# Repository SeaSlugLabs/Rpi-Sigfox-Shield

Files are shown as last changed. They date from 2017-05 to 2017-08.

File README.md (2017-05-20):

# Rpi-Sigfox-Shield
Documentation for Raspberry Pi Sigfox Board

The Wisol WSSFM10R2 is a Sigfox Module based on [Onsemi AX-SFUS](http://www.onsemi.com/pub/Collateral/AX-SFUS-D.PDF)

The WSSFM10R2 uses a UART interface. Simple commands are used to operate the module(see DataSheet).

This Board fits on Raspberry Pi 3, 2, B+, A+, Zero and Zero W.

Find on this repository the information about board. And some python examples to send information via Sigfox Network.

Dont forget to buy our products at [Sea Slug Labs IoT Maker Store](http://www.seasluglabs.io)

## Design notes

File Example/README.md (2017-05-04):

# Rpi-Sigfox-Shield
This is an screenshot Example

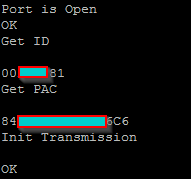
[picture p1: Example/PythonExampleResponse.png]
solarized dualmode


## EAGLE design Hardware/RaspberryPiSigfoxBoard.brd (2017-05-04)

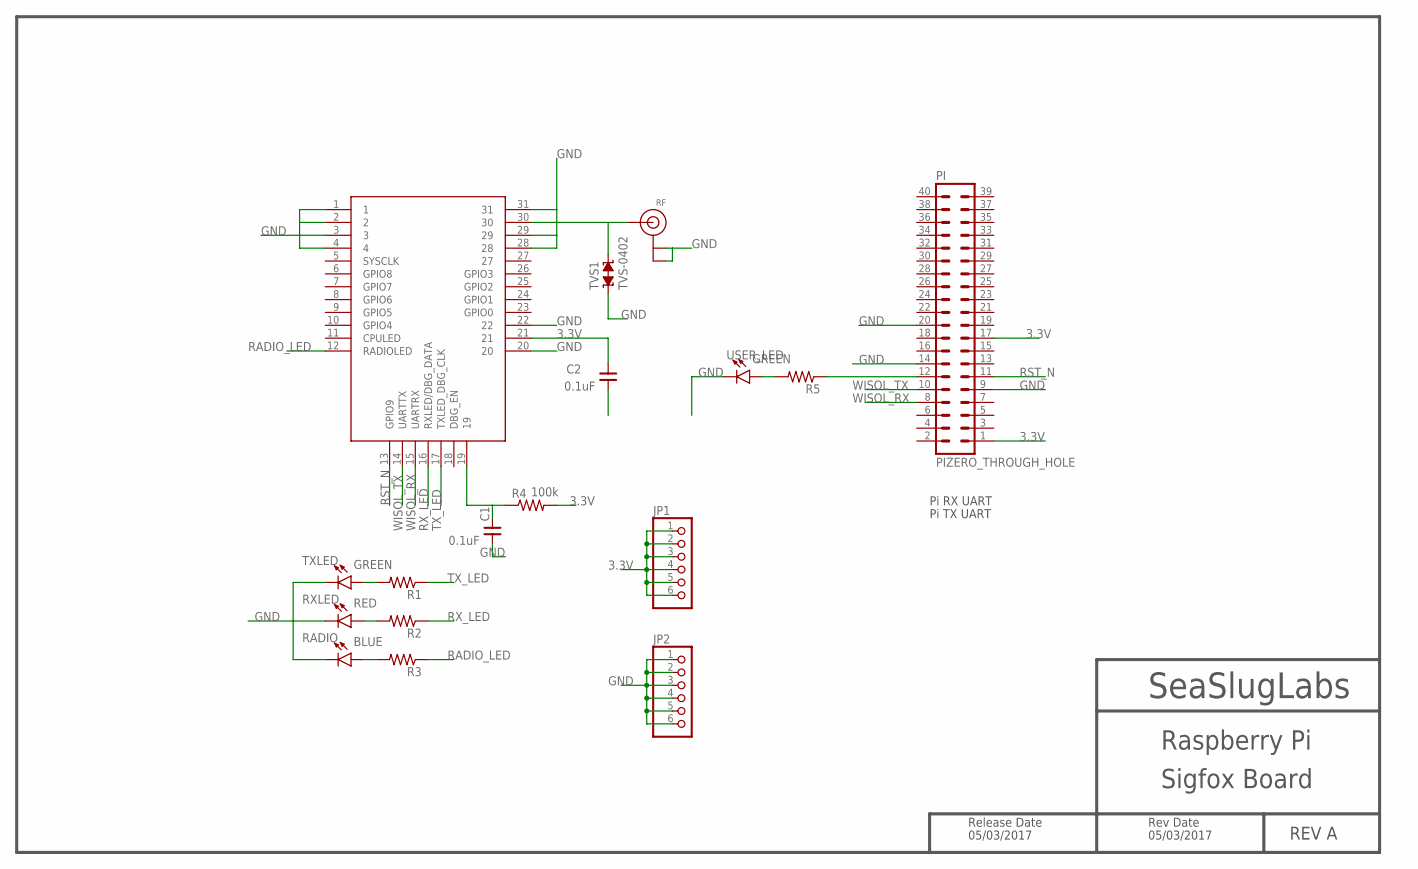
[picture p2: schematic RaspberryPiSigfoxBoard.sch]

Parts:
C1, C2: 0.1uF; 0402
JP1, JP2: PINHD-1X6B; 1X06-BIG
PI: PIZERO_THROUGH_HOLE; PIZERO_THOUGH_HOLE
R1, R2, R3, R5: R-US_R0402; R0402
R4: 100k; R0402
RADIO: BLUE; LED-0603
RF: ANTENNA_U.FL; U.FL
RXLED: RED; LED-0603
TVS1: TVS-0402; TVS0402
TXLED: GREEN; LED-0603
USER_LED: GREEN; LED-0603
WSSFM10R2: WSSFM10R2/R4WSSFM10R2R4; WISOL

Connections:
3.3V: C2.2, JP1.1, JP1.2, JP1.3, JP1.4, JP1.5, JP1.6, PI.1, PI.17, R4.2, WSSFM10R2.21
GND: C1.1, C2.1, JP2.1, JP2.2, JP2.3, JP2.4, JP2.5, JP2.6, PI.9, PI.14, PI.20, RADIO.C, RF.1 (GND), RF.2 (GND), RXLED.C, TVS1.1, TXLED.C, USER_LED.C, WSSFM10R2.1, WSSFM10R2.2, WSSFM10R2.3, WSSFM10R2.4, WSSFM10R2.20, WSSFM10R2.22, WSSFM10R2.28, WSSFM10R2.29, WSSFM10R2.31
unnamed: C1.2, R4.1, WSSFM10R2.19
unnamed: R1.2, TXLED.A
unnamed: R2.2, RXLED.A
unnamed: R3.2, RADIO.A
unnamed: RF.3 (SIGNAL), TVS1.2, WSSFM10R2.30
unnamed: PI.12, R5.1
unnamed: R5.2, USER_LED.A
RADIO_LED: R3.1, WSSFM10R2.12 (RADIOLED)
RST_N: PI.11, WSSFM10R2.13 (GPIO9)
RX_LED: R2.1, WSSFM10R2.16 (RXLED/DBG_DATA)
TX_LED: R1.1, WSSFM10R2.17 (TXLED_DBG_CLK)
WISOL_RX: PI.8, WSSFM10R2.15 (UARTRX)
WISOL_TX: PI.10, WSSFM10R2.14 (UARTTX)

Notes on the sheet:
Pi TX UART
Pi RX UART
SeaSlugLabs
Raspberry Pi
REV A
Sigfox Board
Release Date
05/03/2017
Rev Date

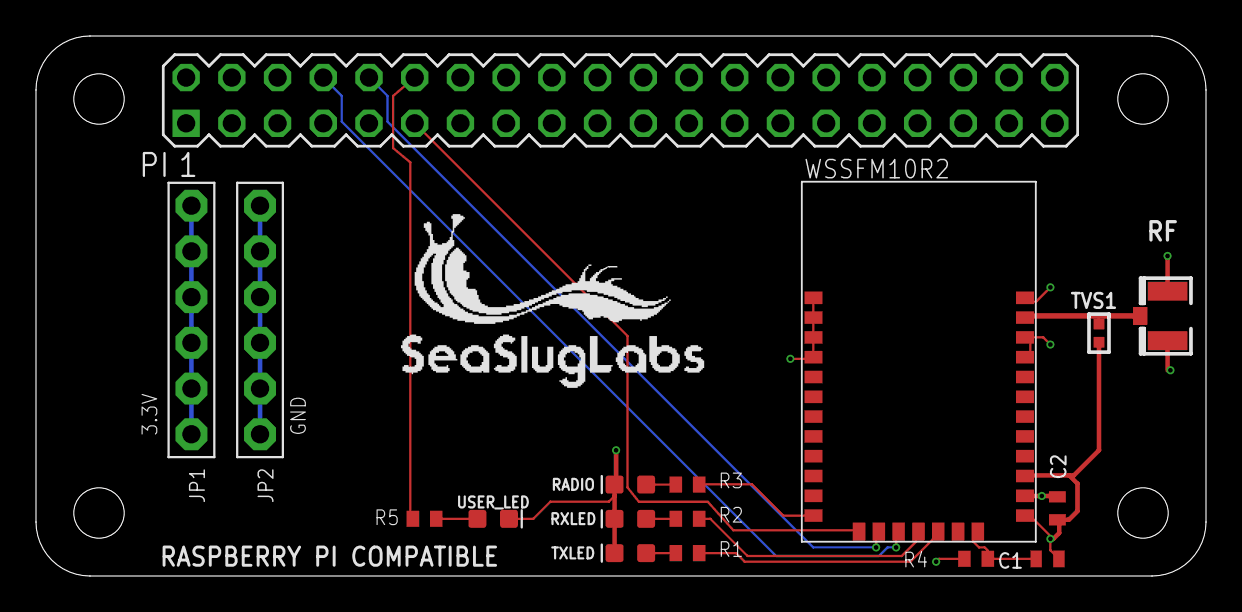
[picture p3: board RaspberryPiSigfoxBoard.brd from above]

Board: 4 copper layers, 65.0 x 30.0 mm, 17 parts (0 on the bottom side), 15 nets.

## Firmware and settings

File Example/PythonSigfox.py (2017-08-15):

from gpiozero import LED
from time import sleep
import serial

red=LED(18)#GPIO pin for USer LED


#Initialize Serial Port
ser=serial.Serial("/dev/ttyS0")
ser.baudrate=9600
##----------

def SigfoxInfo():        
                ser.write("AT\r\n")      #Write AT Command
                data=ser.read(2)         #Response Should be OK
                print(data)

                print("Get ID")
                ser.write("AT$I=10\r\n") #Send Command to Get ID
                data=ser.read(10)
                print(data)

                print("Get PAC")
                ser.write("AT$I=11\r\n") #Send Command to Get ID
                data=ser.read(18)
                print(data)

def SigfoxSend():
                #Initiate a Transmission
                print("Init Transmission")
                sleep(1)
                ser.write("AT$RC\r\n") #Send Command to Reset Macro Channels
                data=ser.read(4)
                print(data)
                ser.write("AT$SF=AABBCCDD\r\n")
                sleep(6)
                data=ser.read(4)        #We should get a OK response
                print(data)



red.on()
sleep(1)
red.off()
sleep(1)
if ser.isOpen:  #Check if port is open
        print("Port is Open")    
        SigfoxInfo()
        SigfoxSend()
else:
        print("Could not Open Serial Port")                
ser.close()

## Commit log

2017-05-04 Add Design Files
    [RaspberryPiSigfoxBoard.brd, RaspberryPiSigfoxBoard.sch]
2017-05-04 Raspberry Pi python Example

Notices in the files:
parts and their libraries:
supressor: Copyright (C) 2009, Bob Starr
